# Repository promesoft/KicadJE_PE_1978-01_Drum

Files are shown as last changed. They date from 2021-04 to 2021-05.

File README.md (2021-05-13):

# KicadJE_PE_1978-01_Drum
Based on https://worldradiohistory.com/UK/Practical-Electronics/70s/Practical-Electronics-1978-01.pdf

# Purpose

## Board 1 - Drum module
Adjustment:  
Mix of snare amt

Gate Input:  
TTL Square

Output Audio:  
+/- 10V AC coupled

## Board 2 - Breadboard helper
Testing out text prints

Adjustment:  
100k Pot to pinheader  
Push button to pinheader

Input/Output:  
3,5mm jack to pinheader  
+-12V from Eurorack 10pin IDC to breadboard pinheaders

## Board 3 - Desktop PDU for Eurojack
Banana jack in  
16 pin Euro power out

# Status - Being assembled
## Initial 
| Stage  | Detail | Status |
| --- | --- | --- |
| create material  | sch | done |
| | pcb | done |
| | gerber | done |
| production  | | delivered |
|  | produced | delivered |
|  | delivered | ok |
## Preliminary validation
| Test  | Detail | Status |
| --- | --- | --- |
| Initial Inspection | PDU | ok mechanical|
| Initial Inspection | BB Helper | ok mechanical - Solder-mask-expansion on copper looks best - better than silk |
| Initial Inspection | Drum Module |  |
| Initial Technical Test | Board 1 |  |
| Initial Product Test | Board1 |  |

## Secondary validation
| Test  | Detail | Status |
| --- | --- |--- |
| Product Test | 1 | |
| Quality | 1 | |
| Long Term Product Test |  |  |
| Power Draw |  | 

## Errata
### Errata - BB Power
### Errata - PDU
R405 not connected to GND

## Issues and Notes
### 

# Pictures
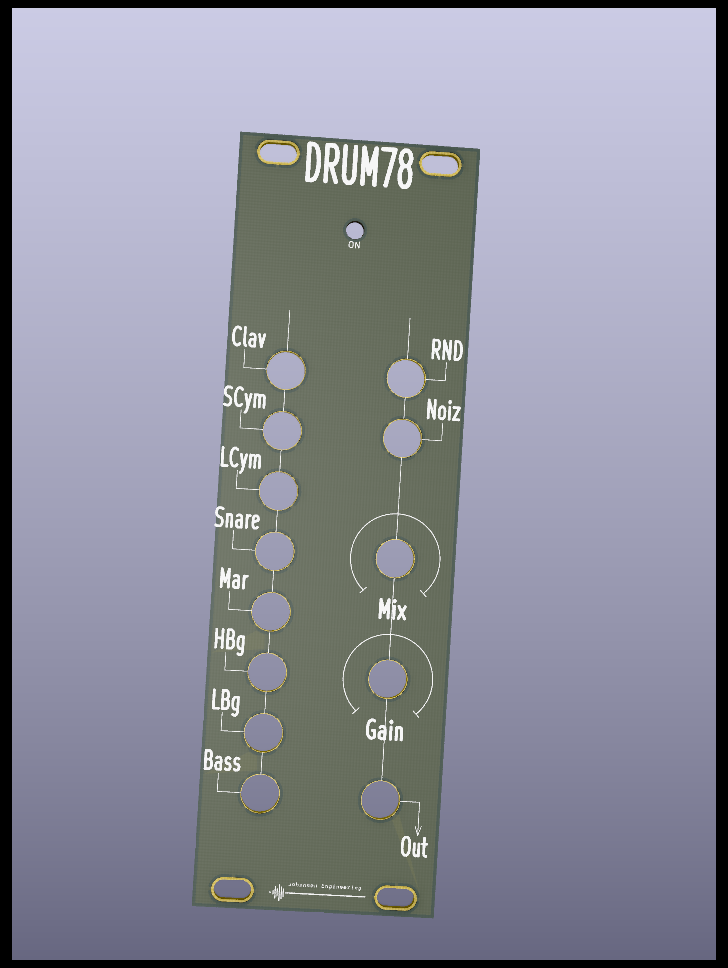
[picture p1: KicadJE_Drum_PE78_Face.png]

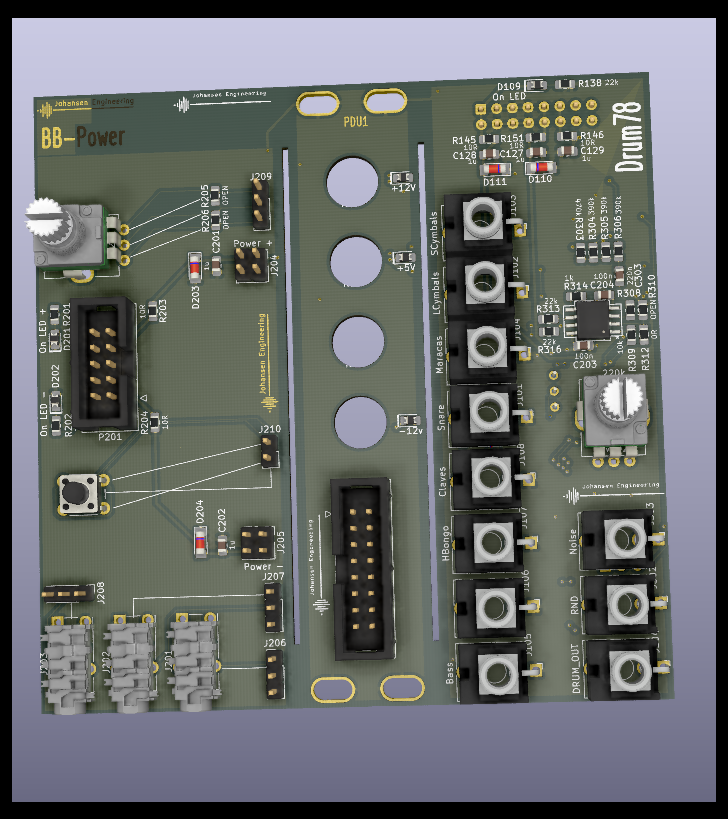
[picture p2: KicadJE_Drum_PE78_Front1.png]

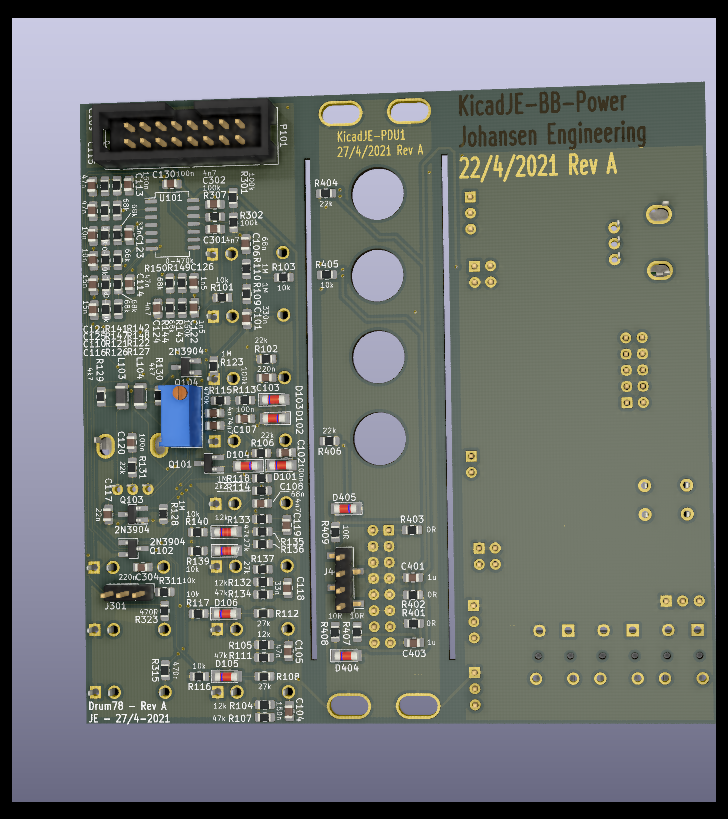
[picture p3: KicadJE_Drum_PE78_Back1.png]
back



# Schematic
## Sch 1
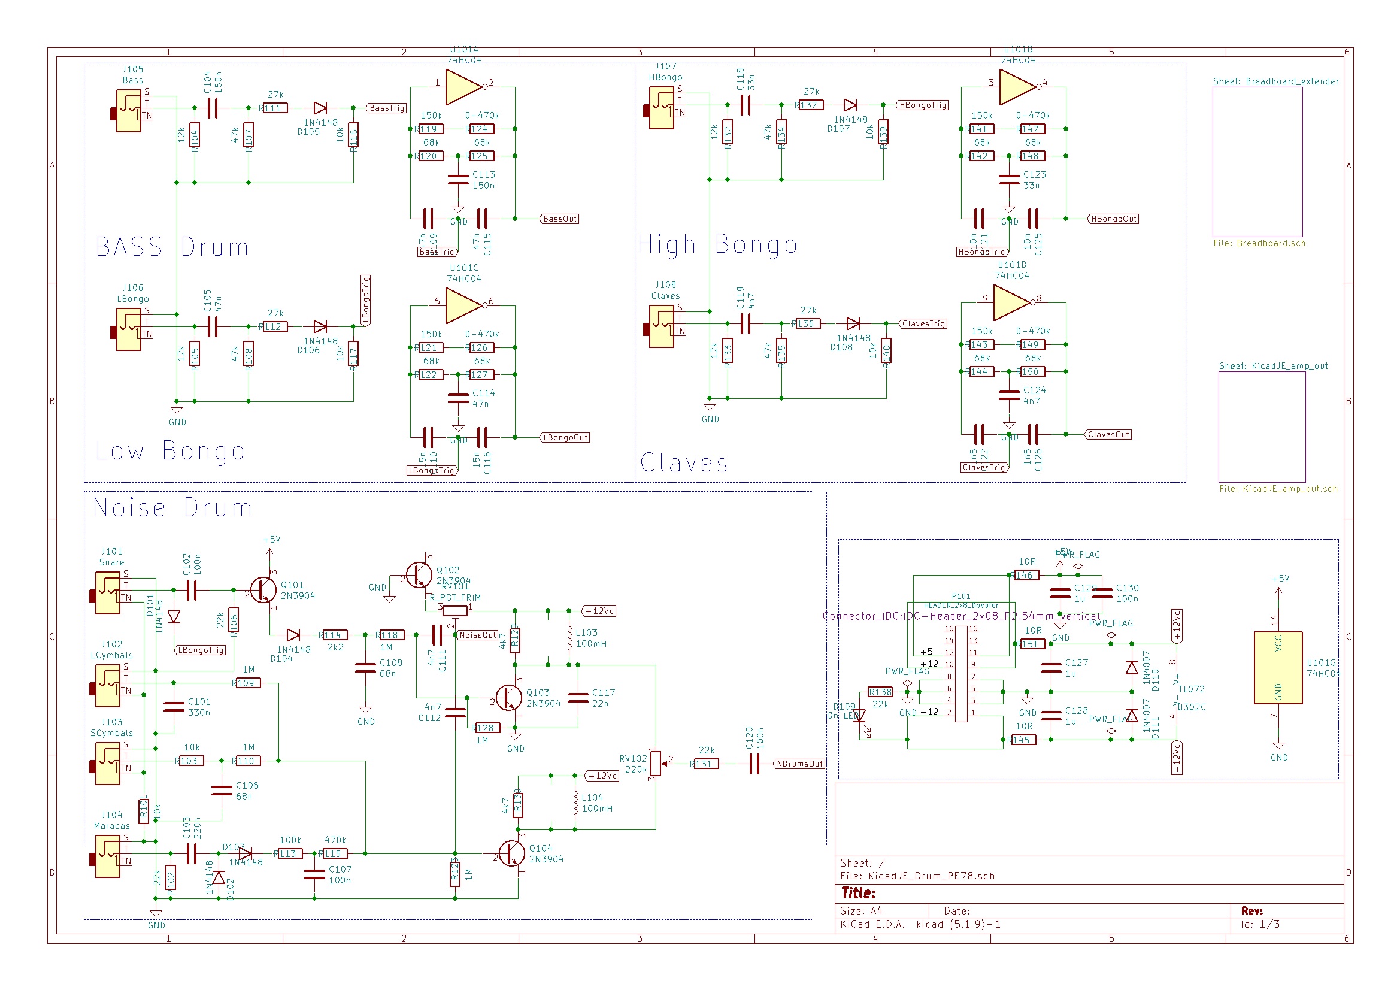
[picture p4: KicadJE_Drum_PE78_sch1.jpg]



# Analysis
## Diag 1

https://worldradiohistory.com/UK/Practical-Electronics/70s/Practical-Electronics-1978-01.pdf

## Prototype


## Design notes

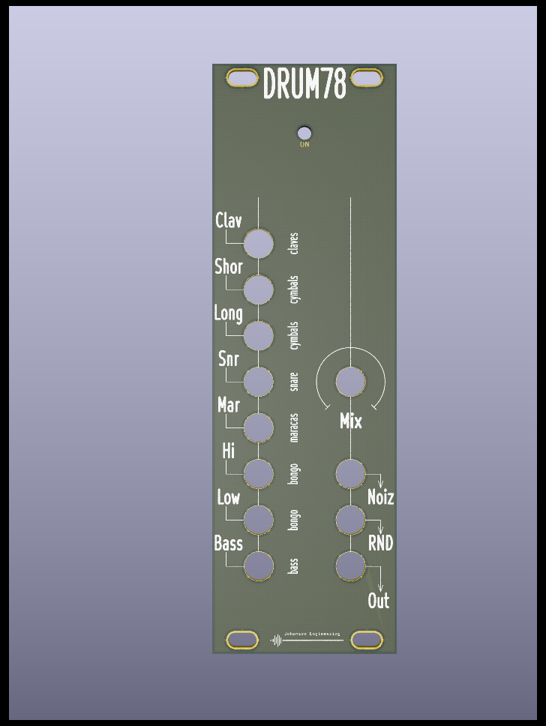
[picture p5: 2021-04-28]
KicadJE_Drum_PE78 - Face.png

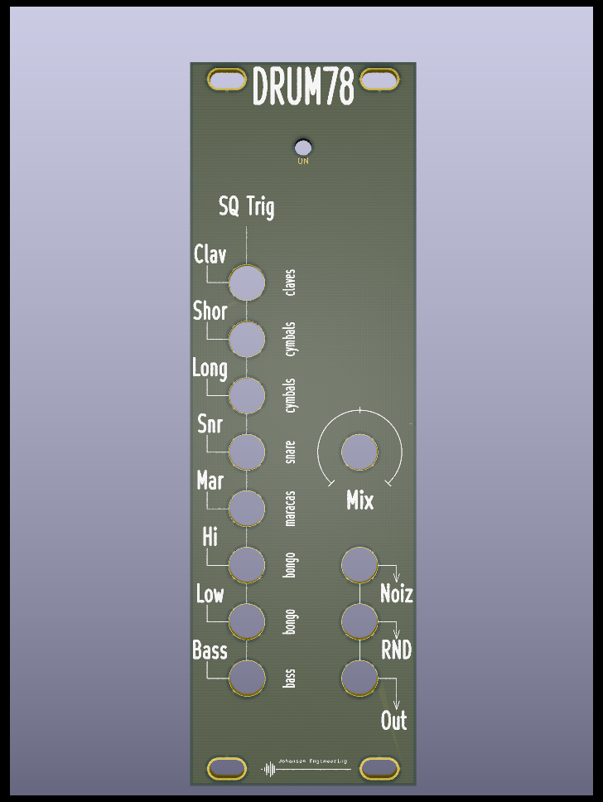
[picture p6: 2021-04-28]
KicadJE_Drum_PE78 - Face1.png

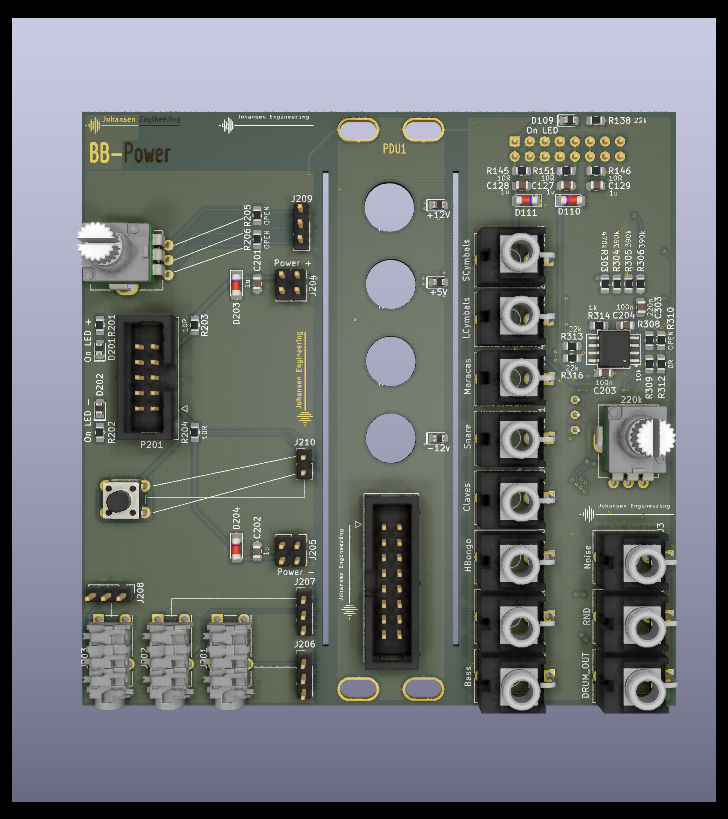
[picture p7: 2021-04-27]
KicadJE_Drum_PE78_Front.png

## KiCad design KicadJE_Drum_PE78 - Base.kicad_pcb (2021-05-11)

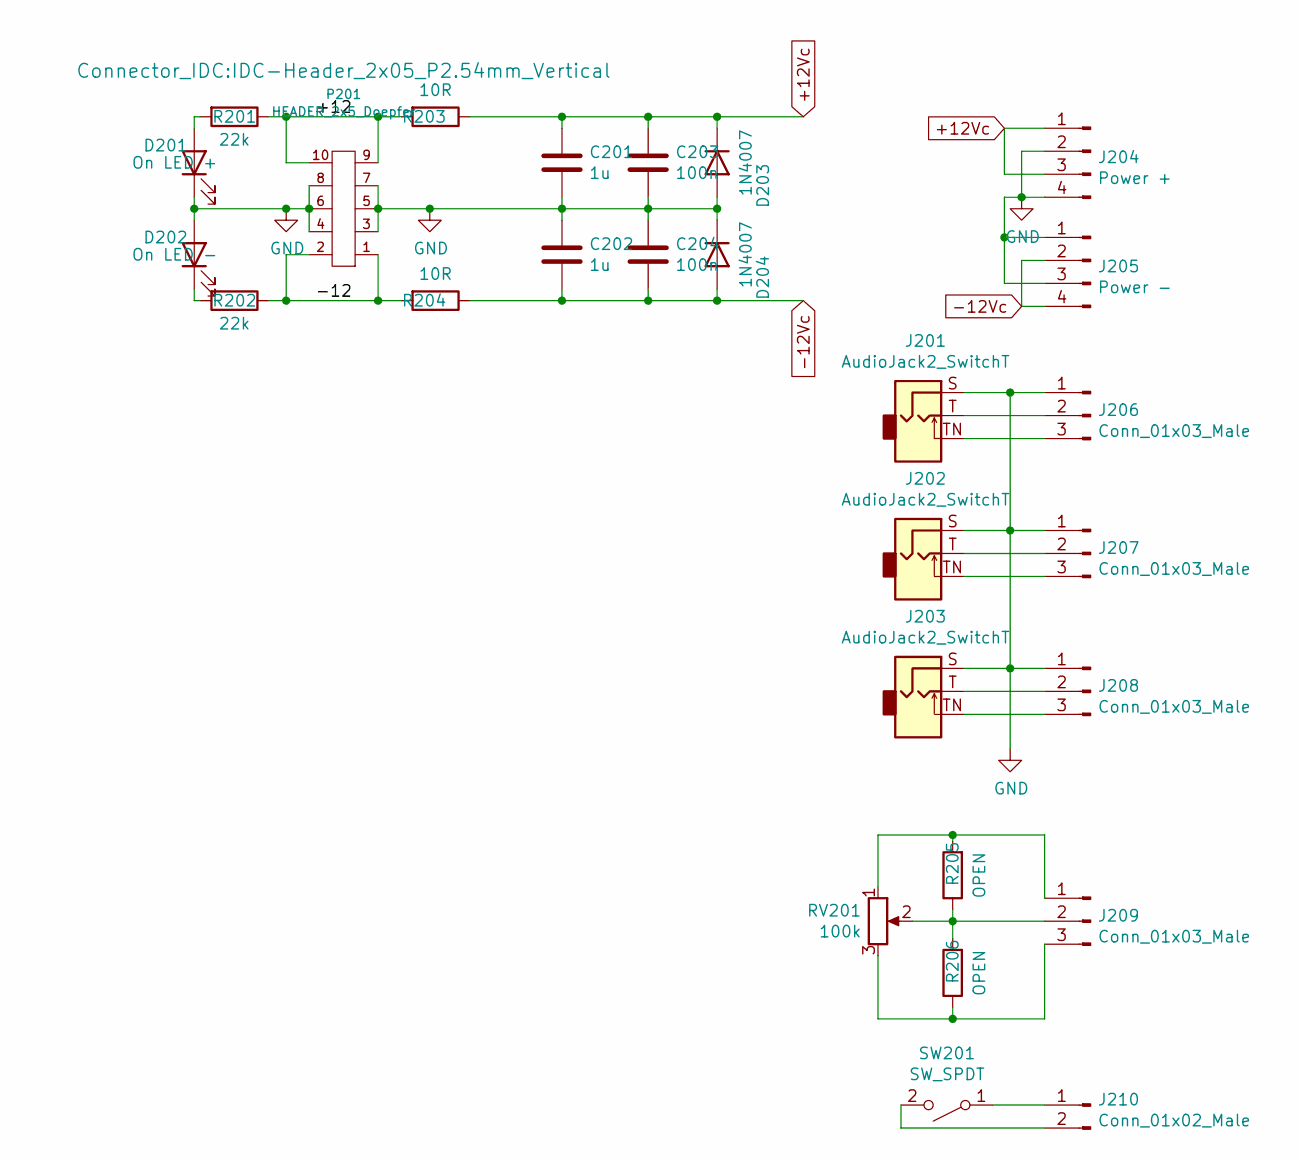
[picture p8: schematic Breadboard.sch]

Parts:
C201, C202: 1u; C_0805_AJ
C203, C204: 100n; C_0805_AJ
D201: On LED +; D_0805_AJ
D202: On LED -; D_0805_AJ
D203, D204: 1N4007; D_MiniMELF
J201, J202, J203: AudioJack2_SwitchT; Jack_3.5mm_Switronic_ST-005-G_horizontal
J204: Power +; PinHeader_2x02_P2.54mm_Vertical
J205: Power -; PinHeader_2x02_P2.54mm_Vertical
J206, J207, J208, J209: Conn_01x03_Male; PinHeader_1x03_P2.54mm_Vertical
J210: Conn_01x02_Male; PinHeader_1x02_P2.54mm_Vertical
P201: HEADER_2x5_Doepfer; IDC-Header_2x05_P2.54mm_Vertical
R201, R202: 22k; R_0805_AJ
R203, R204: 10R; R_0805_AJ
R205, R206: OPEN; R_0805_AJ
RV201: 100k; Potentiometer_China_RK09_Single_Vertical_AJ
SW201: SW_SPDT; SW_PUSH_6mm_H8mm

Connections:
+12Vc: C201.1, C203.1, D203.1 (K), J204.1, J204.3, R203.1; also elsewhere on the board
-12Vc: C202.2, C204.2, D204.2 (A), J205.2, J205.4, R204.1; also elsewhere on the board
/Breadboard_extender/+12: P201.9 (+12), P201.10 (+12), R201.1, R203.2
/Breadboard_extender/-12: P201.1 (-12), P201.2 (-12), R202.1, R204.2
GND: C201.2, C202.1, C203.2, C204.1, D201.1 (K), D202.2 (A), D203.2 (A), D204.1 (K), J201.S, J202.S, J203.S, J204.2, J204.4, J205.1, J205.3, J206.1, J207.1, J208.1, P201.3 (GND), P201.4 (GND), P201.5 (GND), P201.6 (GND), P201.7 (GND), P201.8 (GND); also elsewhere on the board
unnamed: D201.2 (A), R201.2
unnamed: D202.1 (K), R202.2
unnamed: J201.T, J206.2
unnamed: J201.TN, J206.3
unnamed: J202.T, J207.2
unnamed: J202.TN, J207.3
unnamed: J203.T, J208.2
unnamed: J203.TN, J208.3
unnamed: J209.1, R205.2, RV201.1
unnamed: J209.2, R205.1, R206.2, RV201.2
unnamed: J209.3, R206.1, RV201.3
unnamed: J210.1, SW201.1 (A)
unnamed: J210.2, SW201.2 (B)

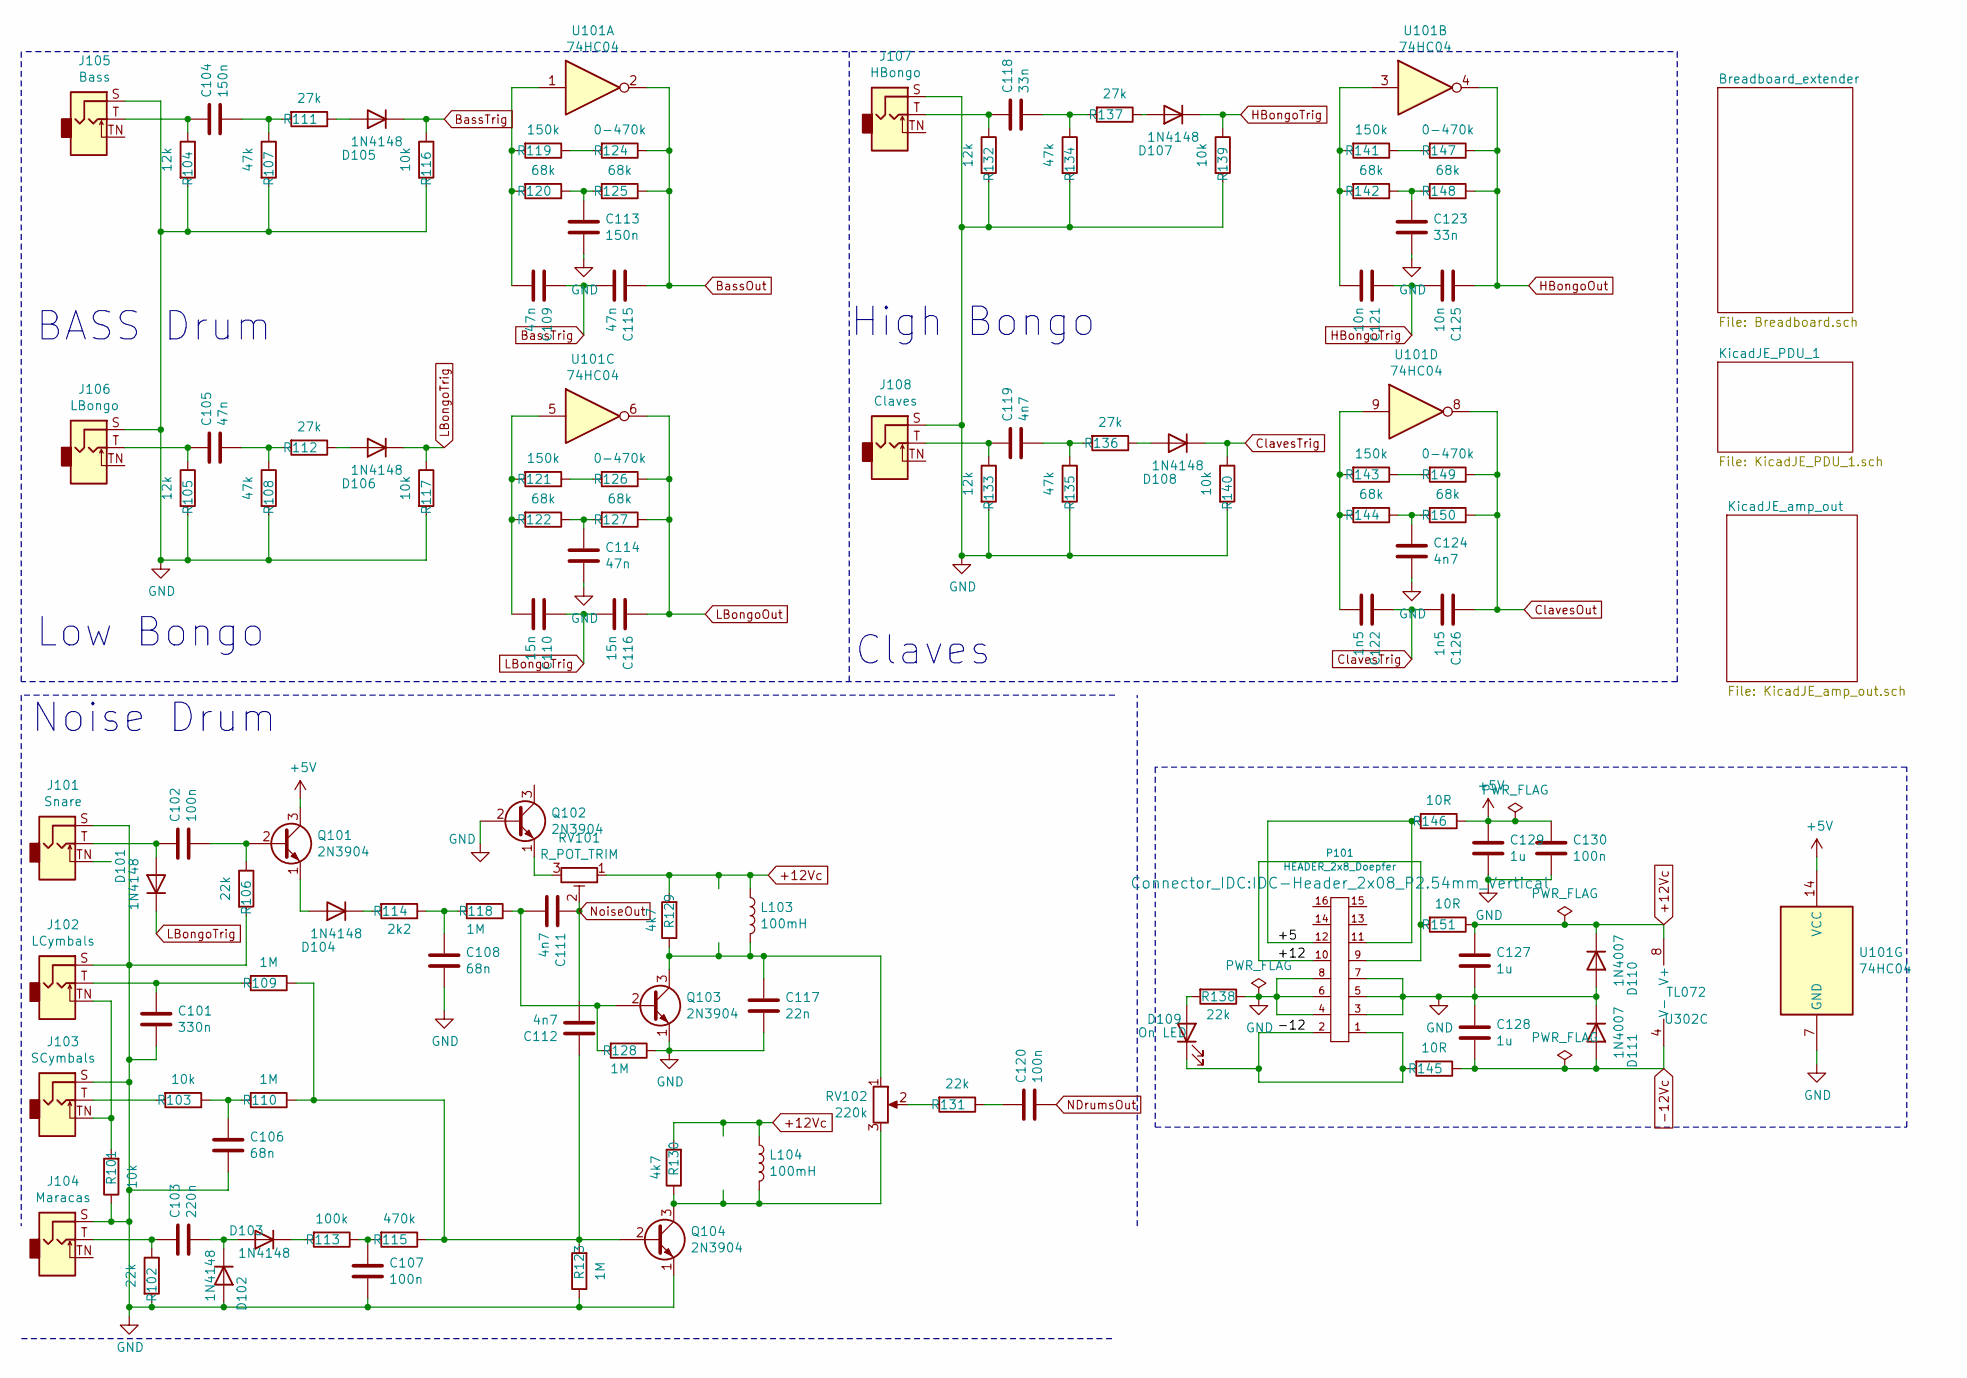
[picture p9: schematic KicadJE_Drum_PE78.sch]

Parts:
C101: 330n; C_0805_AJ
C102, C107, C120, C130: 100n; C_0805_AJ
C103: 220n; C_0805_AJ
C104, C113: 150n; C_0805_AJ
C105, C109, C114, C115: 47n; C_0805_AJ
C106, C108: 68n; C_0805_AJ
C110, C116: 15n; C_0805_AJ
C111, C112, C119, C124: 4n7; C_0805_AJ
C117: 22n; C_0805_AJ
C118, C123: 33n; C_0805_AJ
C121, C125: 10n; C_0805_AJ
C122, C126: 1n5; C_0805_AJ
C127, C128, C129: 1u; C_0805_AJ
D101, D102, D103, D104, D105, D106, D107, D108: 1N4148; D_MiniMELF
D109: On LED; D_0805_AJ
D110, D111: 1N4007; D_MiniMELF
J101: Snare; Jack_3.5mm_QingPu_WQP-PJ398SM_Vertical_CircularHoles
J102: LCymbals; Jack_3.5mm_QingPu_WQP-PJ398SM_Vertical_CircularHoles
J103: SCymbals; Jack_3.5mm_QingPu_WQP-PJ398SM_Vertical_CircularHoles
J104: Maracas; Jack_3.5mm_QingPu_WQP-PJ398SM_Vertical_CircularHoles
J105: Bass; Jack_3.5mm_QingPu_WQP-PJ398SM_Vertical_CircularHoles
J106: LBongo; Jack_3.5mm_QingPu_WQP-PJ398SM_Vertical_CircularHoles
J107: HBongo; Jack_3.5mm_QingPu_WQP-PJ398SM_Vertical_CircularHoles
J108: Claves; Jack_3.5mm_QingPu_WQP-PJ398SM_Vertical_CircularHoles
L103, L104: 100mH; L_1206_3216Metric
P101: HEADER_2x8_Doepfer; IDC-Header_2x08_P2.54mm_Vertical
Q101, Q102, Q103, Q104: 2N3904; SOT-23_Handsoldering
R101, R103, R116, R117, R139, R140: 10k; R_0805_AJ
R102, R106, R131, R138: 22k; R_0805_AJ
R104, R105, R132, R133: 12k; R_0805_AJ
R107, R108, R134, R135: 47k; R_0805_AJ
R109, R110, R118, R123, R128: 1M; R_0805_AJ
R111, R112, R136, R137: 27k; R_0805_AJ
R113: 100k; R_0805_AJ
R114: 2k2; R_0805_AJ
R115: 470k; R_0805_AJ
R119, R121, R141, R143: 150k; R_0805_AJ
R120, R122, R125, R127, R142, R144, R148, R150: 68k; R_0805_AJ
R124, R126, R147, R149: 0-470k; R_0805_AJ
R129, R130: 4k7; R_0805_AJ
R145, R146, R151: 10R; R_0805_AJ
RV101: R_POT_TRIM; Potentiometer_Bourns_3296W_Vertical
RV102: 220k; Potentiometer_China_RK09_Single_Vertical_AJ
U101: 74HC04; SO-14_5.3x10.2mm_P1.27mm
U302: TL072; AJ_SO-8_5.3x6.2mm_P1.27mm

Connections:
+5V: C129.1, C130.1, Q101.3 (C), R146.1, U101.14 (VCC); also elsewhere on the board
+12Vc: C127.1, D110.1 (K), L103.1, L104.1, R129.2, R130.2, R151.1, RV101.1, U302.8 (V+); also elsewhere on the board
-12Vc: C128.2, D111.2 (A), R145.1, U302.4 (V-); also elsewhere on the board
/+5: P101.11 (+5), P101.12 (+5), R146.2
/+12: P101.9 (+12), P101.10 (+12), R151.2
/-12: D109.1 (K), P101.1 (-12), P101.2 (-12), R145.2
BassOut: C115.1, R124.1, R125.1, U101.2; also elsewhere on the board
BassTrig: C109.1, C115.2, D105.1 (K), R116.1
ClavesOut: C126.1, R149.1, R150.1, U101.8; also elsewhere on the board
ClavesTrig: C122.1, C126.2, D108.1 (K), R140.1
GND: C101.2, C106.2, C107.2, C108.2, C113.2, C114.2, C117.2, C123.2, C124.2, C127.2, C128.1, C129.2, C130.2, D102.2 (A), D110.2 (A), D111.1 (K), J101.S, J102.S, J103.S, J104.S, J105.S, J106.S, J107.S, J108.S, P101.3 (GND), P101.4 (GND), P101.5 (GND), P101.6 (GND), P101.7 (GND), P101.8 (GND), Q102.2 (B), Q103.1 (E), Q104.1 (E), R101.1, R102.2, R104.2, R105.2, R106.2, R107.2, R108.2, R116.2, R117.2, R123.1, R128.1, R132.2, R133.2, R134.2, R135.2, R138.1, R139.2, R140.2, U101.7 (GND); also elsewhere on the board
HBongoOut: C125.1, R147.1, R148.1, U101.4; also elsewhere on the board
HBongoTrig: C121.1, C125.2, D107.1 (K), R139.1
LBongoOut: C116.1, R126.1, R127.1, U101.6; also elsewhere on the board
LBongoTrig: C110.1, C116.2, D101.1 (K), D106.1 (K), R117.1
NDrumsOut: C120.2; also elsewhere on the board
unnamed: C101.1, J102.T, R109.2
unnamed: C102.1, D101.2 (A), J101.T
unnamed: C102.2, Q101.2 (B), R106.1
unnamed: C103.1, J104.T, R102.1
unnamed: C103.2, D102.1 (K), D103.2 (A)
unnamed: C104.1, J105.T, R104.1
unnamed: C104.2, R107.1, R111.2
unnamed: C105.1, J106.T, R105.1
unnamed: C105.2, R108.1, R112.2
unnamed: C106.1, R103.1, R110.2
unnamed: C107.1, R113.1, R115.2
unnamed: C108.1, R114.1, R118.2
unnamed: C109.2, R119.2, R120.2, U101.1
unnamed: C110.2, R121.2, R122.2, U101.5
unnamed: C111.2, Q103.2 (B), R118.1, R128.2
unnamed: C112.1, Q104.2 (B), R109.1, R110.1, R115.1, R123.2
unnamed: C113.1, R120.1, R125.2
unnamed: C114.1, R122.1, R127.2
unnamed: C117.1, L103.2, Q103.3 (C), R129.1, RV102.1
unnamed: C118.1, J107.T, R132.1
unnamed: C118.2, R134.1, R137.2
unnamed: C119.1, J108.T, R133.1
unnamed: C119.2, R135.1, R136.2
unnamed: C120.1, R131.1
unnamed: C121.2, R141.2, R142.2, U101.3
unnamed: C122.2, R143.2, R144.2, U101.9
unnamed: C123.1, R142.1, R148.2
unnamed: C124.1, R144.1, R150.2
unnamed: D103.1 (K), R113.2
unnamed: D104.1 (K), R114.2
unnamed: D104.2 (A), Q101.1 (E)
unnamed: D105.2 (A), R111.1
unnamed: D106.2 (A), R112.1
unnamed: D107.2 (A), R137.1
unnamed: D108.2 (A), R136.1
unnamed: D109.2 (A), R138.2
unnamed: J102.TN, J103.TN, R101.2
unnamed: J103.T, R103.2
unnamed: L104.2, Q104.3 (C), R130.1, RV102.3
unnamed: Q102.1 (E), RV101.3
unnamed: R119.1, R124.2
unnamed: R121.1, R126.2
unnamed: R131.2, RV102.2
unnamed: R141.1, R147.2
unnamed: R143.1, R149.2
NoiseOut: C111.1, C112.2, RV101.2; also elsewhere on the board

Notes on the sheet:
BASS Drum
High Bongo
Low Bongo
Claves
Noise Drum

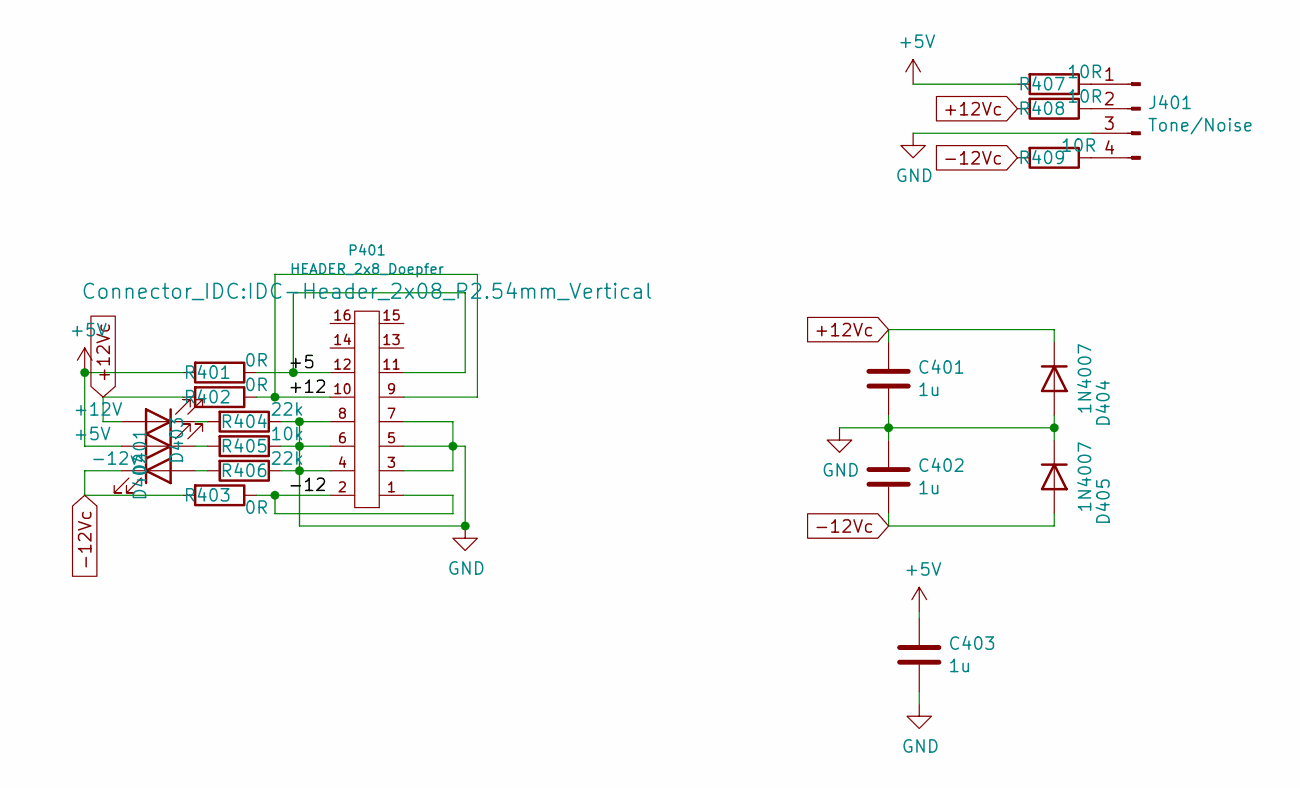
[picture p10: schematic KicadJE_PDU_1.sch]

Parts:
C401, C402, C403: 1u; C_0805_AJ
D401: +12V; D_0805_AJ
D402: +5V; D_0805_AJ
D403: -12v; D_0805_AJ
D404, D405: 1N4007; D_MiniMELF
J401: Tone/Noise; PinHeader_1x04_P2.54mm_Vertical_SMD_Pin1Left
P401: HEADER_2x8_Doepfer; IDC-Header_2x08_P2.54mm_Vertical
R401, R402, R403: 0R; R_0805_AJ
R404, R406: 22k; R_0805_AJ
R405: 10k; R_0805_AJ
R407, R408, R409: 10R; R_0805_AJ

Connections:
+5V: C403.1, D402.2 (A), R401.2, R407.2; also elsewhere on the board
+12Vc: C401.1, D401.2 (A), D404.1 (K), R402.2, R408.2; also elsewhere on the board
-12Vc: C402.2, D403.1 (K), D405.2 (A), R403.2, R409.2; also elsewhere on the board
/KicadJE_PDU_1/+5: P401.11 (+5), P401.12 (+5), R401.1
/KicadJE_PDU_1/+12: P401.9 (+12), P401.10 (+12), R402.1
/KicadJE_PDU_1/-12: P401.1 (-12), P401.2 (-12), R403.1
GND: C401.2, C402.1, C403.2, D404.2 (A), D405.1 (K), J401.3, P401.3 (GND), P401.4 (GND), P401.5 (GND), P401.6 (GND), P401.7 (GND), P401.8 (GND), R404.1, R405.1, R406.1; also elsewhere on the board
unnamed: D401.1 (K), R404.2
unnamed: D402.1 (K), R405.2
unnamed: D403.2 (A), R406.2
unnamed: J401.1, R407.1
unnamed: J401.2, R408.1
unnamed: J401.4, R409.1

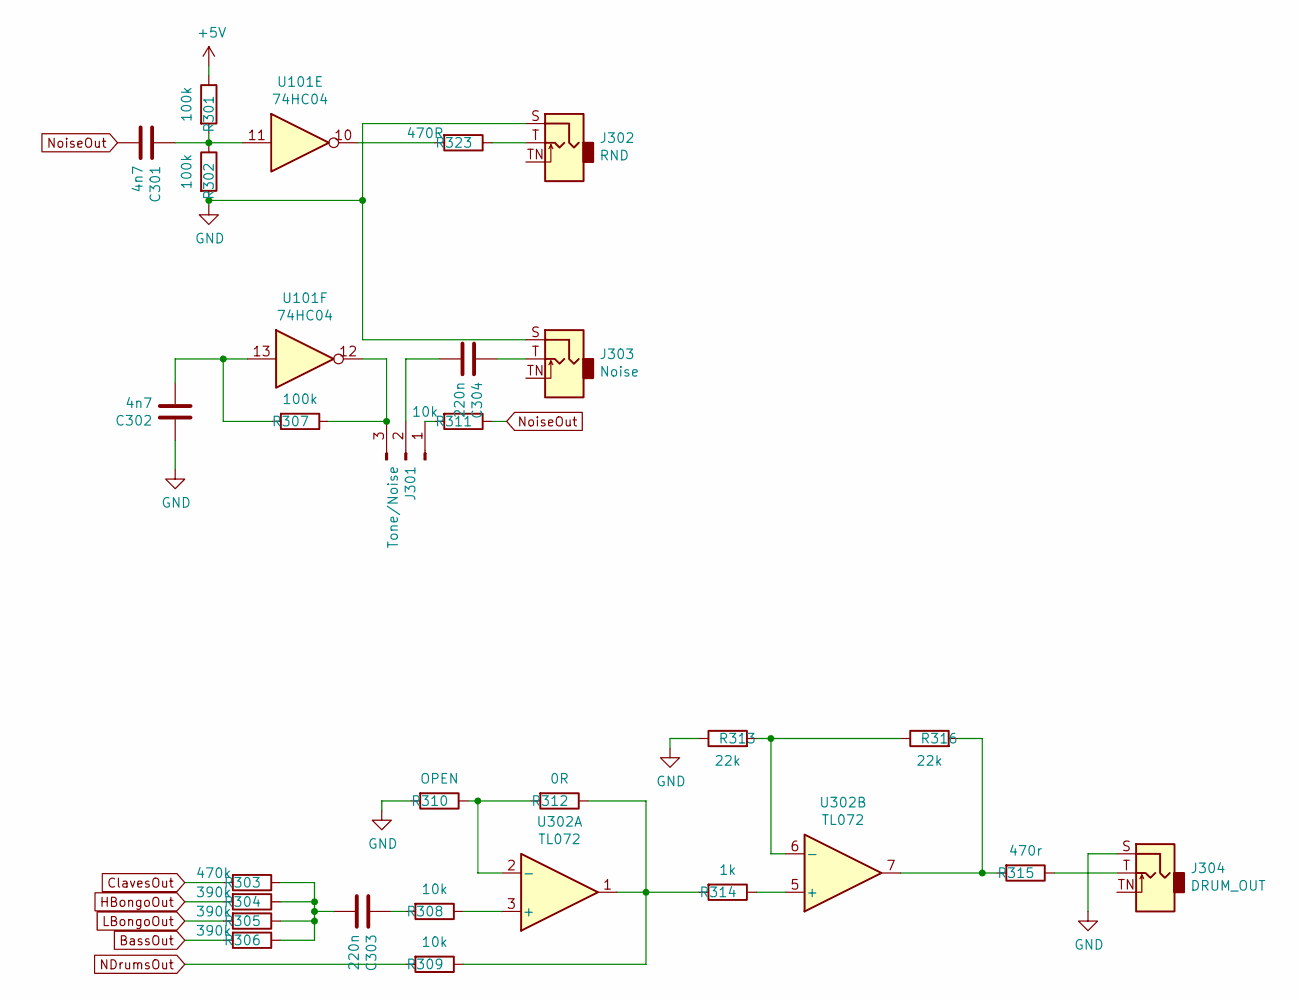
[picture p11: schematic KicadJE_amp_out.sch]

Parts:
C301, C302: 4n7; C_0805_AJ
C303, C304: 220n; C_0805_AJ
J301: Tone/Noise; PinHeader_1x03_P2.54mm_Vertical
J302: RND; Jack_3.5mm_QingPu_WQP-PJ398SM_Vertical_CircularHoles
J303: Noise; Jack_3.5mm_QingPu_WQP-PJ398SM_Vertical_CircularHoles
J304: DRUM_OUT; Jack_3.5mm_QingPu_WQP-PJ398SM_Vertical_CircularHoles
R301, R302, R307: 100k; R_0805_AJ
R303: 470k; R_0805_AJ
R304, R305, R306: 390k; R_0805_AJ
R308, R309, R311: 10k; R_0805_AJ
R310: OPEN; R_0805_AJ
R312: 0R; R_0805_AJ
R313, R316: 22k; R_0805_AJ
R314: 1k; R_0805_AJ
R315: 470r; R_0805_AJ
R323: 470R; R_0805_AJ
U101: 74HC04; SO-14_5.3x10.2mm_P1.27mm
U302: TL072; AJ_SO-8_5.3x6.2mm_P1.27mm

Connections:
+5V: R301.1; also elsewhere on the board
BassOut: R306.2; also elsewhere on the board
ClavesOut: R303.2; also elsewhere on the board
GND: C302.1, J302.S, J303.S, J304.S, R302.2, R310.2, R313.1; also elsewhere on the board
HBongoOut: R304.2; also elsewhere on the board
LBongoOut: R305.2; also elsewhere on the board
NDrumsOut: R309.2; also elsewhere on the board
unnamed: C301.1, R301.2, R302.1, U101.11
unnamed: C302.2, R307.2, U101.13
unnamed: C303.1, R308.2
unnamed: C303.2, R303.1, R304.1, R305.1, R306.1
unnamed: C304.1, J303.T
unnamed: C304.2, J301.2
unnamed: J301.1, R311.2
unnamed: J301.3, R307.1, U101.12
unnamed: J302.T, R323.1
unnamed: J304.T, R315.1
unnamed: R308.1, U302.3 (+)
unnamed: R309.1, R312.1, R314.2, U302.1
unnamed: R310.1, R312.2, U302.2 (-)
unnamed: R313.2, R316.1, U302.6 (-)
unnamed: R314.1, U302.5 (+)
unnamed: R315.2, R316.2, U302.7
unnamed: R323.2, U101.10
NoiseOut: C301.2, R311.1; also elsewhere on the board

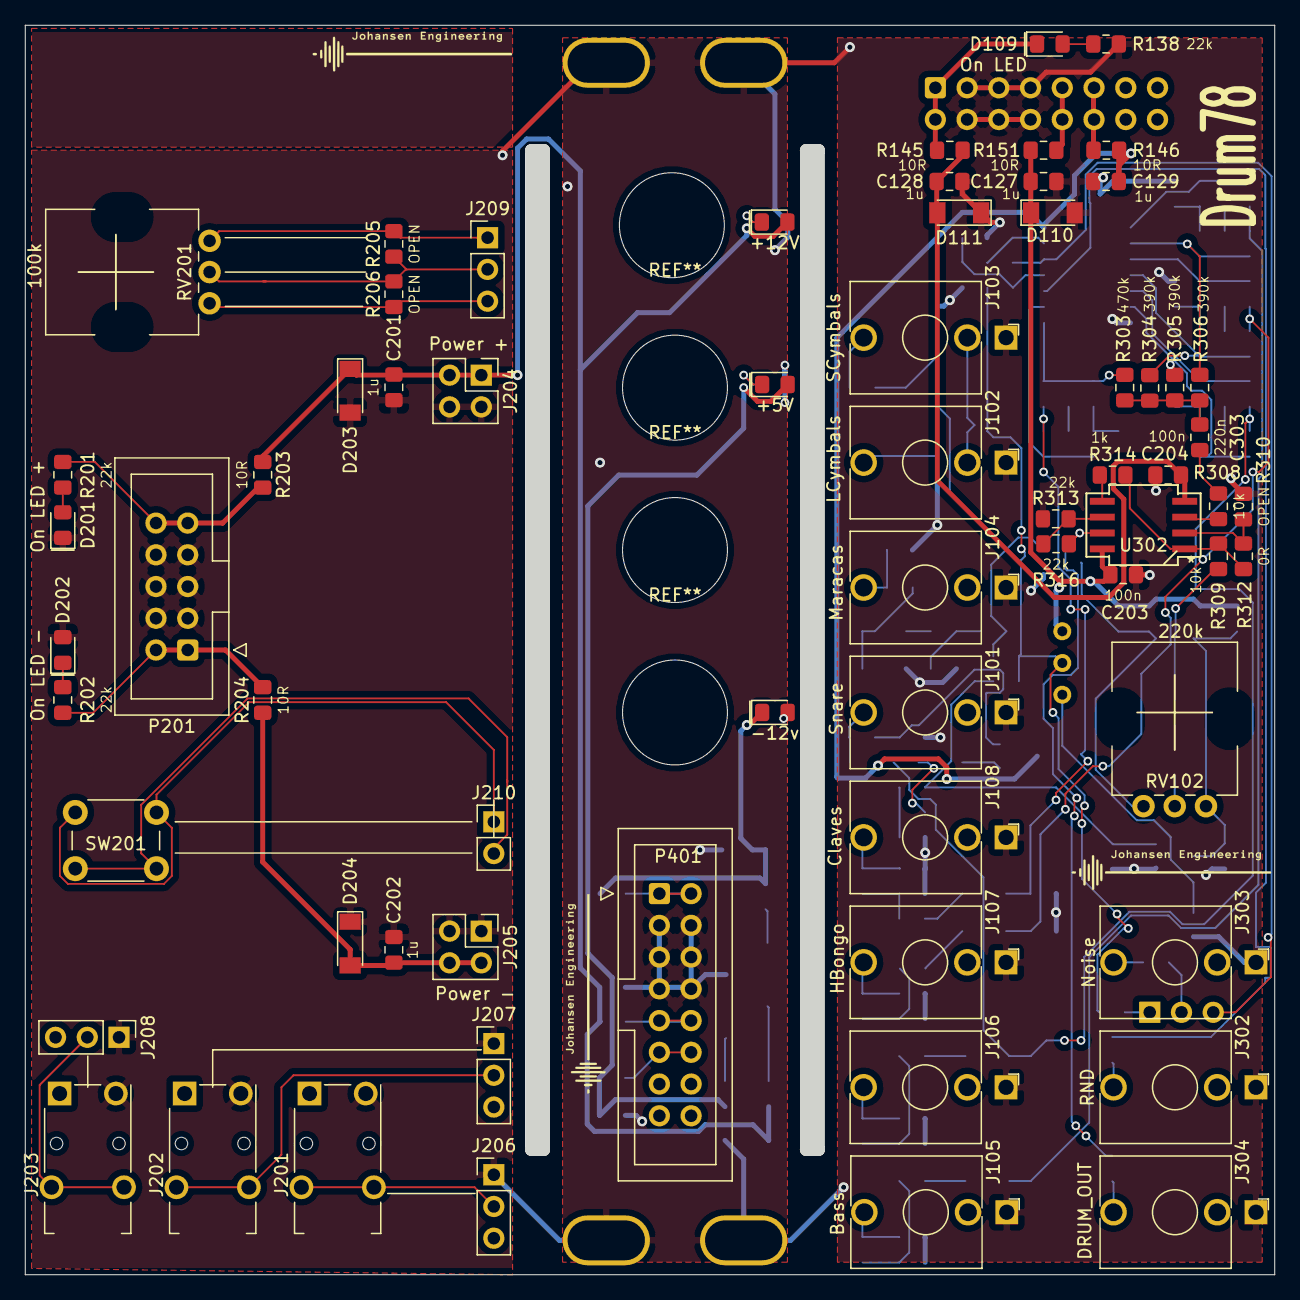
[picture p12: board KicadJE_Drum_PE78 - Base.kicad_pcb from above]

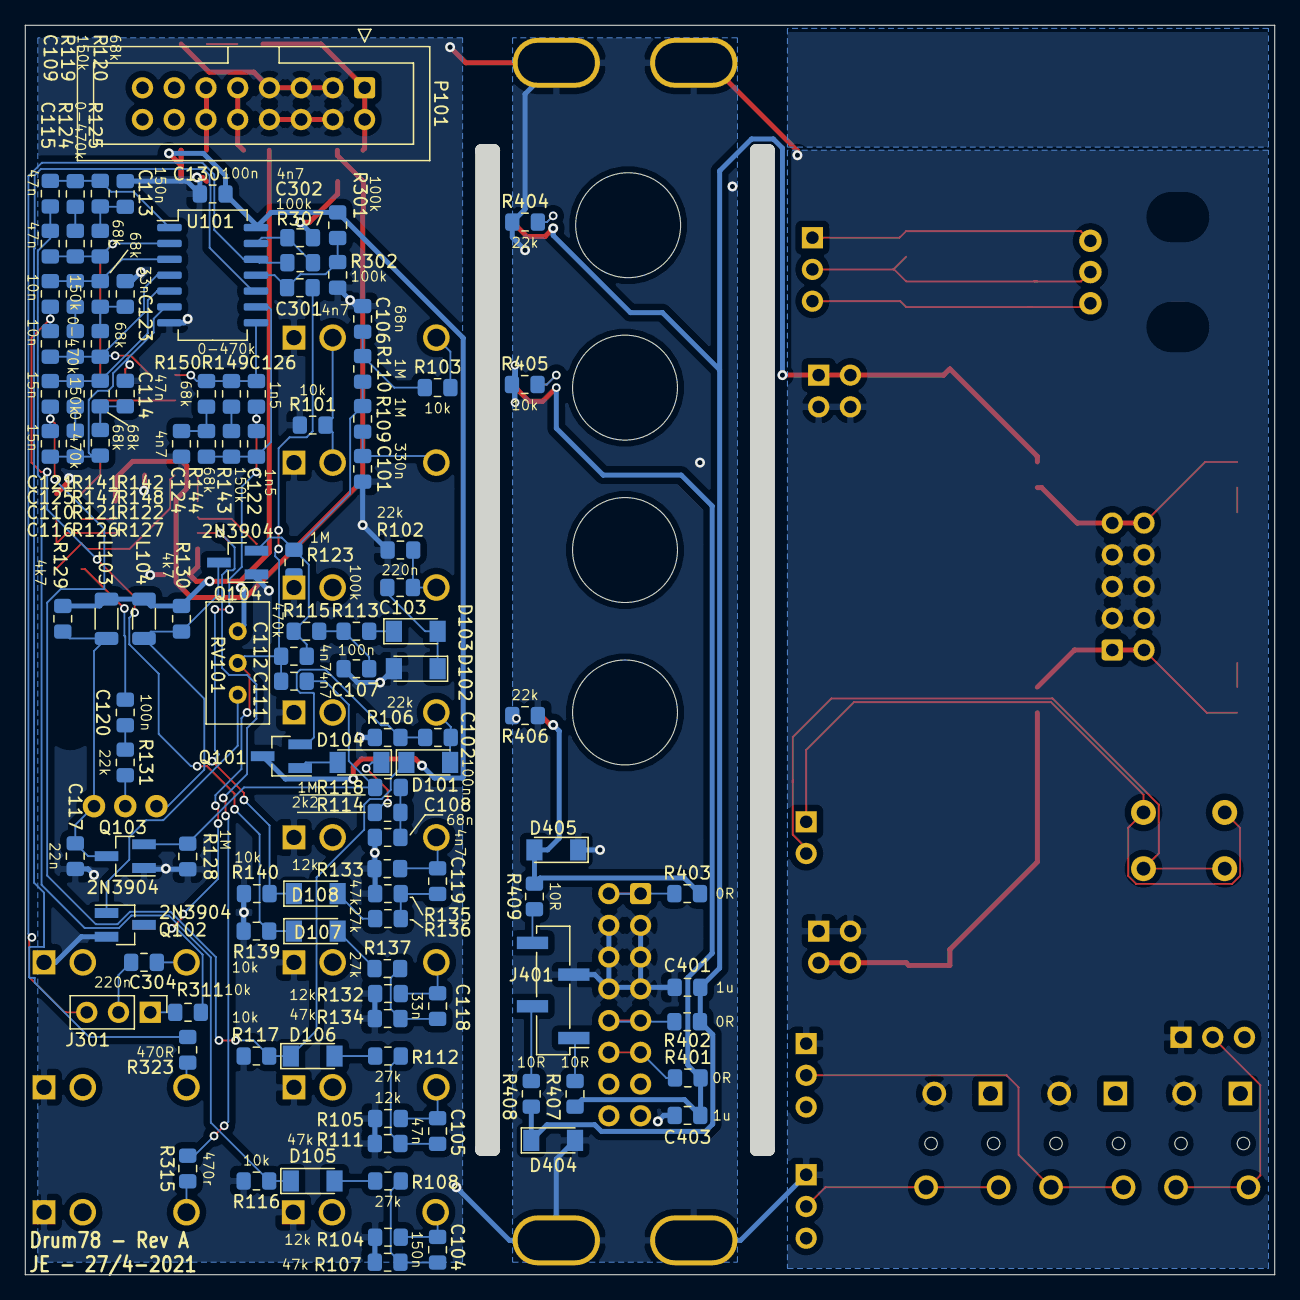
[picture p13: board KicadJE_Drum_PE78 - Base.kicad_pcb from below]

Board: 2 copper layers, 100.0 x 100.0 mm, 185 parts (119 on the bottom side), 100 nets.

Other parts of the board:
H103, H103#2, H103#3, H103#4: MountingHole_Pad; MountingHole_Eurorack3

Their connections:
GND: H103.1, H103#2.1, H103#3.1, H103#4.1; also elsewhere on the board

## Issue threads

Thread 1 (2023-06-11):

Did you end up testing the drum board?

os144046, 2023-06-11:
I am going to be building these drums soon, and was curious if yours worked, and if you might have any random advice about this circuit. Thanks!

promesoft, 2023-06-11:
Hi

I had a lot of projects going on at that time, and at the time I got the boards, my life turned upside down, and I never got around to solder them and tweak them - so unfortunately I cant vouch for them yet.

If you chose to continue with them I am happy to hear about your progress and any problems you may encounter. I would be delighted if you find and fix any problems you may find - or perhaps we may fix it together if needed.

Looking fwd to hearing more!

os144046, 2023-06-11:
That definitely happens. Glad to hear back. I will at least be breadboarding them soon!

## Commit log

2021-03-17 Project started
    [KicadJE_Drum_PE78.kicad_pcb, KicadJE_Drum_PE78.sch]
2021-03-17 init sch
    [KicadJE_Counts2_1.sch, KicadJE_Drum_PE78_2.sch]
2021-04-14 Drum sheet started
    [KicadJE_Counts2_1.sch, KicadJE_Drum_PE78.kicad_pcb, KicadJE_Drum_PE78.sch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]
2021-04-18 Breadboard sch
    [Breadboard.sch, KicadJE_Drum_PE78.sch]
2021-04-19 Sinus osc done - sch
    [KicadJE_Drum_PE78.sch]
2021-04-20 Noise drums
    [Breadboard.sch, KicadJE_Drum_PE78.sch, KicadJE_amp_out.sch]
2021-04-20 Amp out
    [KicadJE_Drum_PE78.sch, KicadJE_amp_out.sch]
2021-04-21 sch amp
    [KicadJE_amp_out.sch]
2021-04-21 Update misc diags
    [Breadboard.sch, KicadJE_Drum_PE78.sch, KicadJE_amp_out.sch]
2021-04-21 ERC Performed - changed symbol for 16pin pwr
    [KicadJE_Drum_PE78.sch]
2021-04-21 Footprint adj
    [KicadJE_Drum_PE78.sch, KicadJE_amp_out.sch]
2021-04-22 Faceplate etc
    [KicadJE_Drum_PE78.sch, KicadJE_amp_out.sch]
2021-04-22 BB Power
    [KicadJE_Drum_PE78.kicad_pcb]
2021-04-22 3D upd
    [KicadJE_Drum_PE78.kicad_pcb]
2021-04-26 AC coupled noise
    [KicadJE_Drum_PE78.sch, KicadJE_amp_out.sch]
2021-04-26 Power to TL072
    [KicadJE_Drum_PE78.sch]
2021-04-26 THT Coils removed
    [KicadJE_Drum_PE78.sch]
2021-04-26 Components initially placed
    [KicadJE_Drum_PE78.kicad_pcb]
2021-04-26 Schematic pictures
2021-04-27 Breadboard routed
    [Breadboard.sch, KicadJE_Drum_PE78.kicad_pcb, KicadJE_amp_out.sch]
2021-04-27 decoupling for Op Amp
    [Breadboard.sch]
2021-04-27 BB Logo - GND planes
    [Breadboard.sch, KicadJE_Drum_PE78.kicad_pcb, KicadJE_Drum_PE78.sch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]
2021-04-27 PDU unit added
    [Breadboard.sch, KicadJE_Drum_PE78.sch, KicadJE_PDU_1.sch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]
2021-04-27 Front Component Silk
    [KicadJE_Drum_PE78.kicad_pcb]
2021-04-27 Labels back
    [KicadJE_Drum_PE78.kicad_pcb]
2021-04-27 Board labels
    [KicadJE_Drum_PE78.kicad_pcb]
2021-04-28 Prep for different gerber
    [KicadJE_Drum_PE78 - Base.kicad_pcb, KicadJE_Drum_PE78 - Face.kicad_pcb, KicadJE_Drum_PE78_org.kicad_pcb]
2021-04-28 Faceplate + Gerber
    [KicadJE_Drum_PE78 - Face-B_Cu.gbl, KicadJE_Drum_PE78 - Face-B_Mask.gbs, KicadJE_Drum_PE78 - Face-B_Paste.gbp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]
2021-04-28 Create KicadJE_Drum_PE78 - Base.zip
2021-04-28 Faceplate - not matching base - fix
    [KicadJE_Drum_PE78 - Face-B_Cu.gbl, KicadJE_Drum_PE78 - Face-B_Mask.gbs, KicadJE_Drum_PE78 - Face-B_Paste.gbp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]
2021-04-28 base removed from face pcb
    [KicadJE_Drum_PE78 - Face.kicad_pcb]
2021-04-28 Face tweaked
    [KicadJE_Drum_PE78 - Face.kicad_pcb]
2021-04-28 Face Gerber
    [KicadJE_Drum_PE78 - Face-B_Cu.gbl, KicadJE_Drum_PE78 - Face-B_Mask.gbs, KicadJE_Drum_PE78 - Face-B_Paste.gbp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]
2021-04-28 Gerber Face
    [KicadJE_Drum_PE78 - Face - WRONG.kicad_pcb]
2021-05-11 Fix PCB Errors
    [KicadJE_Drum_PE78 - Base.kicad_pcb]
